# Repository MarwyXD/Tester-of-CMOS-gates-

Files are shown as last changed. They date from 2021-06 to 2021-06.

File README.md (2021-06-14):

# Tester-of-CMOS-gates-
# This is the tester of CMOS gates, they’re used a lot in electronics so i said to myself that i could create one, the reason i’m giving it online is that you all can later create code for your own CMOS gates, couse i only created program for six gates (7432, 7408, 4001, 7400, 7420, 7404/7414), i will later work on some more codes for this tester too, but for now i’ll keep it up to you, if you will create code for some more gates.

# As i mentioned in the discription of the eagle files, you should only use the .sch file, the board isn’t finished, it is due to i selected to only route the bottom layer (i dont have any PCBs with two layers), but you can create gerber files and send it for example to JLC PCB, they will do it very precisly (probably).

# The tester_CMOS_hradel.ino file is my original code for the tester. 

# Thank you.

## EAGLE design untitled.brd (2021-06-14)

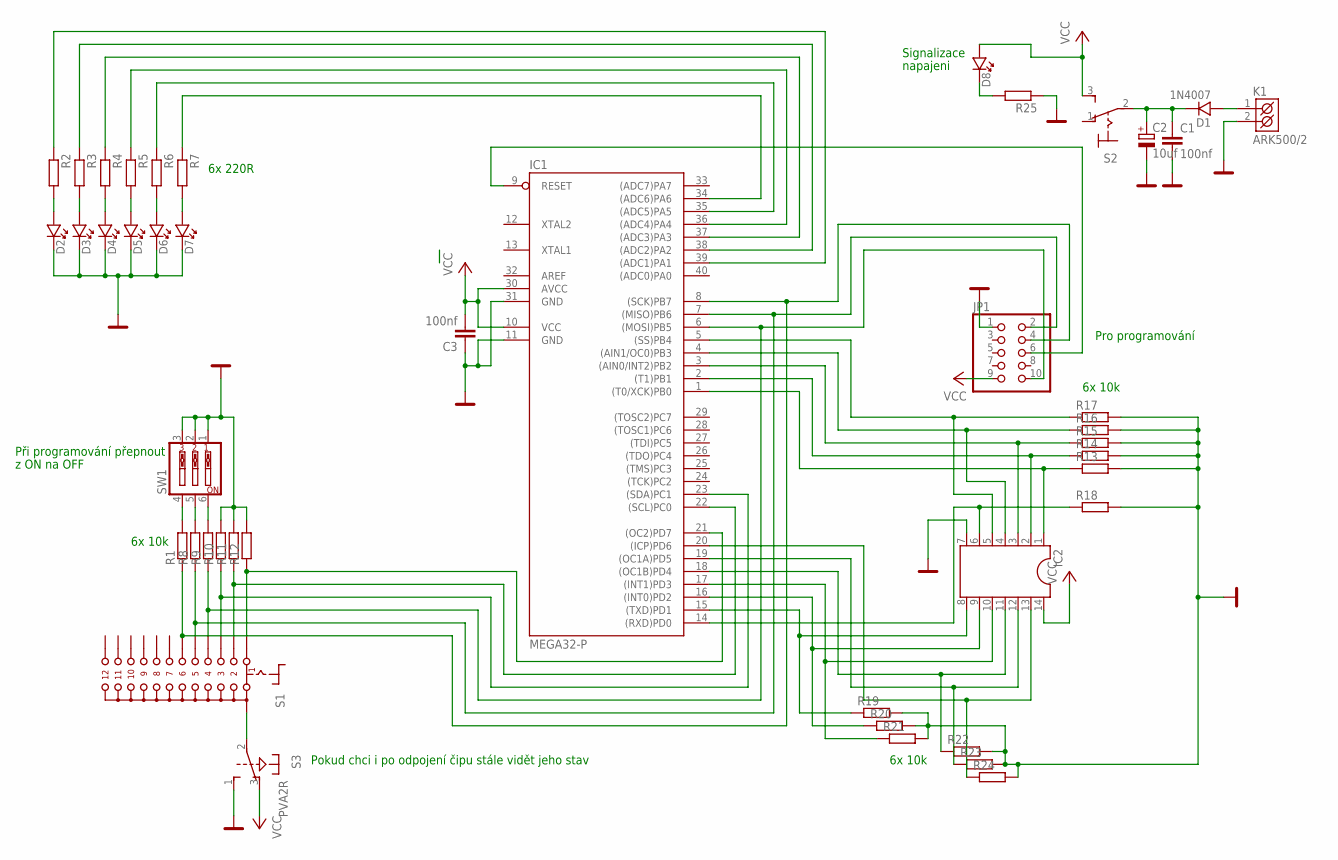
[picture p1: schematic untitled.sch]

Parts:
C1, C3: 100nf; C050-025X075
C2: 10uf; E5-8,5
D1: 1N4007; DO41
D2, D3, D4, D5, D6, D7, D8: LED_5
IC1: MEGA32-P; DIL40
IC2: DIL14
JP1: PINHD-2X5; 2X05
K1: ARK500/2
R1, R2, R3, R4, R5, R6, R7, R8, R9, R10, R11, R12, R13, R14, R15, R16, R17, R18, R19, R20, R21, R22, R23, R24, R25: R-EU_0207/10; 0207/10
S1: CK101X12
S2: 320-916
S3: PVA2R
SW1: SW_DIP-3; EDG-03

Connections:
GND: C1.2, C2.-, C3.1, D2.K, D3.K, D4.K, D5.K, D6.K, D7.K, IC1.11 (GND), IC1.31 (GND), IC2.7, JP1.1, K1.2 (K2), R10.2, R11.2, R12.2, R13.2, R14.2, R15.2, R16.2, R17.2, R18.2, R19.2, R20.2, R21.2, R22.2, R23.2, R24.2, R25.1, S3.1 (S), SW1.1, SW1.2, SW1.3
unnamed: R1.2, SW1.4
unnamed: D2.A, R2.2
unnamed: D3.A, R3.2
unnamed: D4.A, R4.2
unnamed: S1.A, S3.2
unnamed: IC1.1 ((T0/XCK)PB0), IC2.1, R13.1
unnamed: IC1.8 ((SCK)PB7), JP1.4, R1.1, S1.6
unnamed: IC1.9 (RESET), JP1.6
unnamed: D5.A, R5.2
unnamed: R8.2, SW1.5
unnamed: R9.2, SW1.6
unnamed: D6.A, R6.2
unnamed: D7.A, R7.2
unnamed: IC1.39 ((ADC1)PA1), R2.1
unnamed: IC1.38 ((ADC2)PA2), R3.1
unnamed: IC1.37 ((ADC3)PA3), R4.1
unnamed: IC1.36 ((ADC4)PA4), R5.1
unnamed: IC1.35 ((ADC5)PA5), R6.1
unnamed: IC1.34 ((ADC6)PA6), R7.1
unnamed: IC1.2 ((T1)PB1), IC2.2, R14.1
unnamed: IC1.7 ((MISO)PB6), JP1.2, R8.1, S1.5
unnamed: IC1.6 ((MOSI)PB5), JP1.10, R9.1, S1.4
unnamed: IC1.23 ((SDA)PC1), R10.1, S1.3
unnamed: IC1.22 ((SCL)PC0), R11.1, S1.2
unnamed: IC1.21 ((OC2)PD7), R12.1, S1.1
unnamed: IC1.3 ((AIN0/INT2)PB2), IC2.3, R15.1
unnamed: IC1.4 ((AIN1/OC0)PB3), IC2.4, R16.1
unnamed: IC1.5 ((SS)PB4), IC2.5, R17.1
unnamed: IC1.14 ((RXD)PD0), IC2.6, R18.1
unnamed: C1.1, C2.+, D1.K, S2.2
unnamed: D1.A, K1.1 (K1)
unnamed: IC1.15 ((TXD)PD1), IC2.8, R19.1
unnamed: IC1.16 ((INT0)PD2), IC2.9, R20.1
unnamed: IC1.17 ((INT1)PD3), IC2.10, R21.1
unnamed: IC1.18 ((OC1B)PD4), IC2.11, R22.1
unnamed: IC1.19 ((OC1A)PD5), IC2.12, R23.1
unnamed: IC1.20 ((ICP)PD6), IC2.13, R24.1
unnamed: D8.K, R25.2
VCC: C3.2, D8.A, IC1.10 (VCC), IC1.30 (AVCC), IC2.14, JP1.9, S2.3 (S), S3.3 (O)

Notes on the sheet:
6x 10k
6x 220R
Při programování přepnout
z ON na OFF
Pokud chci i po odpojení čipu stále vidět jeho stav
Signalizace
napajeni
Pro programování

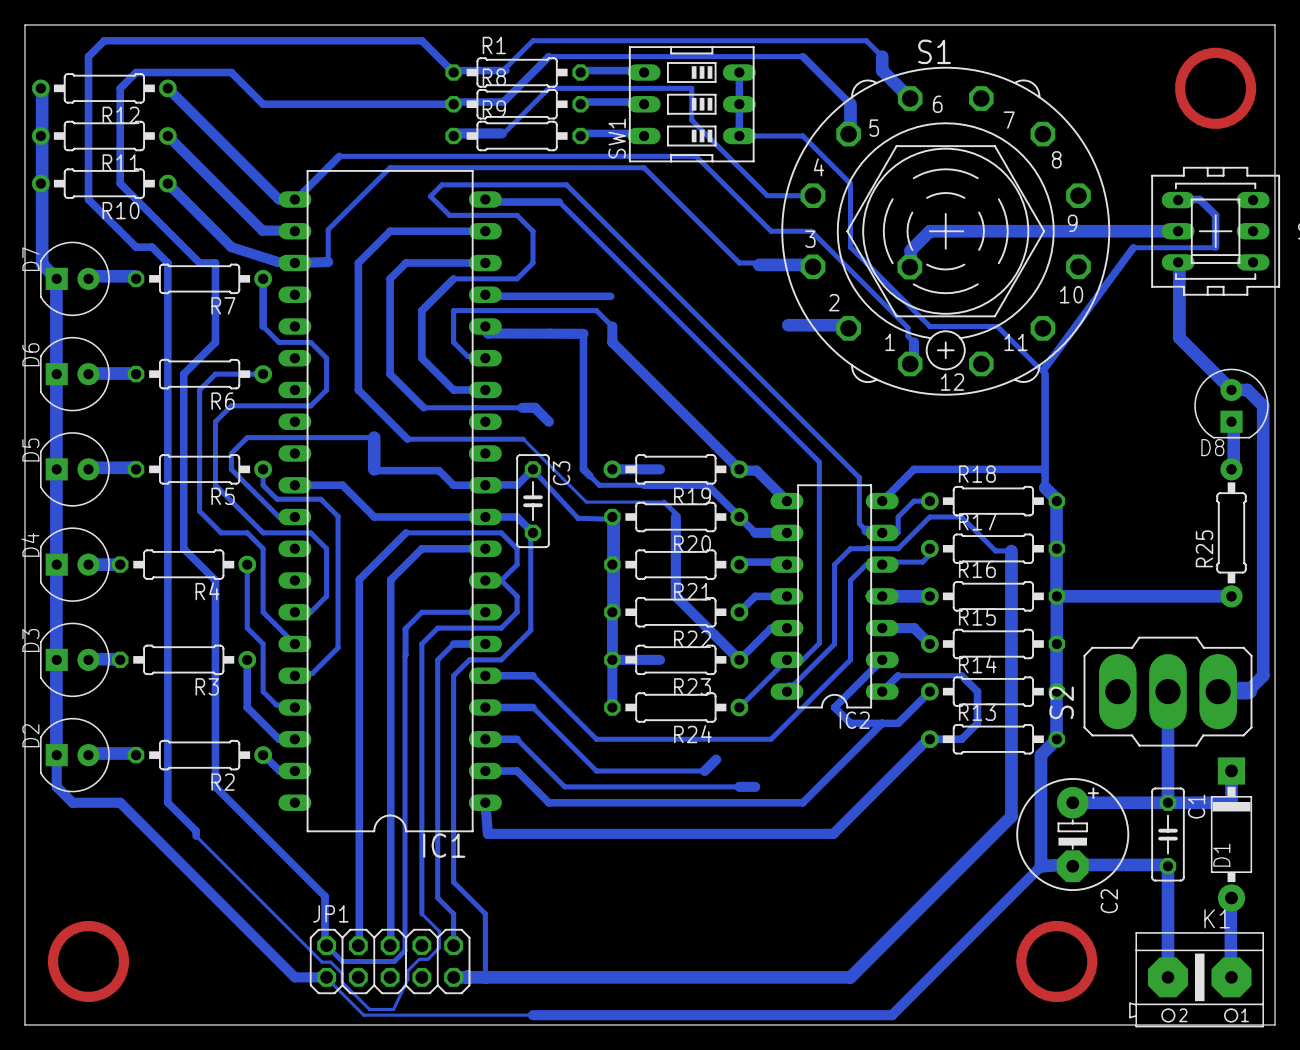
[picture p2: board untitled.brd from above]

Board: 2 copper layers, 100.0 x 80.0 mm, 44 parts (0 on the bottom side), 40 nets.

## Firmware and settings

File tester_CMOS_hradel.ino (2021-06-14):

//piny a proměnné pro čtení vstupů
int tlacitko_1 = 15;
int tlacitko_2 = 16;
int tlacitko_3 = 17;
int tlacitko_4 = 5;
int tlacitko_5 = 6;
int tlacitko_6 = 7;

//piny pro signalizaci 
int prvni_hradlo = 30;
int druhy_hradlo = 29;
int treti_hradlo = 28;
int ctvrty_hradlo = 27;
int paty_hradlo = 26;
int sesty_hradlo = 25;

//piny pro testování
int test_1 = 0;
int test_2 = 1;
int test_3 = 2;
int test_4 = 3;
int test_5 = 4;
int test_6 = 8;
int test_7 = 9;
int test_8 = 10;
int test_9 = 11;
int test_10 = 12;
int test_11= 13;
int test_12 = 14;


void setup() {
  // put your setup code here, to run once:

//tlacitko
pinMode(tlacitko_1, INPUT);
pinMode(tlacitko_2, INPUT);
pinMode(tlacitko_3, INPUT);
pinMode(tlacitko_4, INPUT);
pinMode(tlacitko_5, INPUT);
pinMode(tlacitko_6, INPUT);

//zobrazovani stavů
pinMode(prvni_hradlo, OUTPUT);
pinMode(druhy_hradlo, OUTPUT);
pinMode(treti_hradlo, OUTPUT);
pinMode(ctvrty_hradlo, OUTPUT);
pinMode(paty_hradlo, OUTPUT);
pinMode(sesty_hradlo, OUTPUT);

}

void loop() {
  // put your main code here, to run repeatedly:

int tlacitko_1_state = digitalRead(tlacitko_1);
int tlacitko_2_state = digitalRead(tlacitko_2);
int tlacitko_3_state = digitalRead(tlacitko_3);
int tlacitko_4_state = digitalRead(tlacitko_4);
int tlacitko_5_state = digitalRead(tlacitko_5);
int tlacitko_6_state = digitalRead(tlacitko_6);

//OR (7432)
if(tlacitko_1_state == HIGH && tlacitko_2_state == LOW && tlacitko_3_state == LOW && tlacitko_4_state == LOW && tlacitko_5_state == LOW && tlacitko_6_state == LOW){
  OR();
}
//AND (----)
else if(tlacitko_1_state == LOW && tlacitko_2_state == HIGH && tlacitko_3_state == LOW && tlacitko_4_state == LOW && tlacitko_5_state == LOW && tlacitko_6_state == LOW){
  AND(); 
}
//NOR (4001)
else if(tlacitko_1_state == LOW && tlacitko_2_state == LOW && tlacitko_3_state == HIGH && tlacitko_4_state == LOW && tlacitko_5_state == LOW && tlacitko_6_state == LOW){
  NOR(); 
}
//NAND (7400)
else if(tlacitko_1_state == LOW && tlacitko_2_state == LOW && tlacitko_3_state == LOW && tlacitko_4_state == HIGH && tlacitko_5_state == LOW && tlacitko_6_state == LOW){
  NAND();
}
//4NAND (7420)
else if(tlacitko_1_state == LOW && tlacitko_2_state == LOW && tlacitko_3_state == LOW && tlacitko_4_state == LOW && tlacitko_5_state == HIGH && tlacitko_6_state == LOW){
  NAND4();
}
//INV (7404/7414)
else if(tlacitko_1_state == LOW && tlacitko_2_state == LOW && tlacitko_3_state == LOW && tlacitko_4_state == LOW && tlacitko_5_state == LOW && tlacitko_6_state == HIGH){
  INV();
}

}

void OR(){                                            //Inputy jsou Dig. piny 2, 8, 9, 12

  digitalWrite(paty_hradlo, LOW);
  digitalWrite(sesty_hradlo, LOW);
  
  //definice pinů pro testy
  pinMode(test_1, OUTPUT);
  pinMode(test_2, OUTPUT);
  pinMode(test_3, INPUT);
  int test_3_state = digitalRead(test_3);

  pinMode(test_4, OUTPUT);
  pinMode(test_5, OUTPUT);
  pinMode(test_6, INPUT);
  int test_6_state = digitalRead(test_6);
  
  pinMode(test_9, OUTPUT);
  pinMode(test_8, OUTPUT);
  pinMode(test_7, INPUT);
  int test_7_state = digitalRead(test_7);

  pinMode(test_12, OUTPUT);
  pinMode(test_11, OUTPUT);
  pinMode(test_10, INPUT);
  int test_10_state = digitalRead(test_10);

  digitalWrite(test_1, HIGH);
  digitalWrite(test_2, HIGH);
  digitalWrite(test_4, HIGH);
  digitalWrite(test_5, HIGH);
  digitalWrite(test_9, HIGH);
  digitalWrite(test_8, HIGH);
  digitalWrite(test_12, HIGH);
  digitalWrite(test_11, HIGH);

  if(test_3_state == HIGH){
    digitalWrite(prvni_hradlo, HIGH);
  }
  else{
    digitalWrite(prvni_hradlo, LOW);
  }

  if(test_6_state == HIGH){
    digitalWrite(druhy_hradlo, HIGH);
  }
  else{
    digitalWrite(druhy_hradlo, LOW);
  }

  if(test_7_state == HIGH){
    digitalWrite(treti_hradlo, HIGH);
  }
  else{
    digitalWrite(treti_hradlo, LOW);
  }

  if(test_10_state == HIGH){
    digitalWrite(ctvrty_hradlo, HIGH);
  }
  else{
    digitalWrite(ctvrty_hradlo, LOW);
  }
 
}

void AND(){                                                //Inputy jsou Dig. piny 2, 8, 9, 12

  digitalWrite(paty_hradlo, LOW);
  digitalWrite(sesty_hradlo, LOW);
  
  //definice pinů pro testy
  pinMode(test_1, OUTPUT);
  pinMode(test_2, OUTPUT);
  pinMode(test_3, INPUT);
  int test_3_state = digitalRead(test_3);

  pinMode(test_4, OUTPUT);
  pinMode(test_5, OUTPUT);
  pinMode(test_6, INPUT);
  int test_6_state = digitalRead(test_6);
  
  pinMode(test_9, OUTPUT);
  pinMode(test_8, OUTPUT);
  pinMode(test_7, INPUT);
  int test_7_state = digitalRead(test_7);

  pinMode(test_12, OUTPUT);
  pinMode(test_11, OUTPUT);
  pinMode(test_10, INPUT);
  int test_10_state = digitalRead(test_10);

  digitalWrite(test_1, HIGH);
  digitalWrite(test_2, HIGH);
  digitalWrite(test_4, HIGH);
  digitalWrite(test_5, HIGH);
  digitalWrite(test_9, HIGH);
  digitalWrite(test_8, HIGH);
  digitalWrite(test_12, HIGH);
  digitalWrite(test_11, HIGH);

  if(test_3_state == HIGH){
    digitalWrite(prvni_hradlo, HIGH);
  }
  else{
    digitalWrite(prvni_hradlo, LOW);
  }

  if(test_6_state == HIGH){
    digitalWrite(druhy_hradlo, HIGH);
  }
  else{
    digitalWrite(druhy_hradlo, LOW);
  }

  if(test_7_state == HIGH){
    digitalWrite(treti_hradlo, HIGH);
  }
  else{
    digitalWrite(treti_hradlo, LOW);
  }

  if(test_10_state == HIGH){
    digitalWrite(ctvrty_hradlo, HIGH);
  }
  else{
    digitalWrite(ctvrty_hradlo, LOW);
  }
}

void NOR(){

  digitalWrite(paty_hradlo, LOW);
  digitalWrite(sesty_hradlo, LOW);
  
  //definice pinů pro testy
  pinMode(test_1, OUTPUT);
  pinMode(test_2, OUTPUT);
  pinMode(test_3, INPUT);
  int test_3_state = digitalRead(test_3);

  pinMode(test_6, OUTPUT);
  pinMode(test_5, OUTPUT);
  pinMode(test_4, INPUT);
  int test_4_state = digitalRead(test_4);
  
  pinMode(test_7, OUTPUT);
  pinMode(test_8, OUTPUT);
  pinMode(test_9, INPUT);
  int test_9_state = digitalRead(test_9);

  pinMode(test_12, OUTPUT);
  pinMode(test_11, OUTPUT);
  pinMode(test_10, INPUT);
  int test_10_state = digitalRead(test_10);

  digitalWrite(test_1, LOW);
  digitalWrite(test_2, LOW);
  digitalWrite(test_6, LOW);
  digitalWrite(test_5, LOW);
  digitalWrite(test_7, LOW);
  digitalWrite(test_8, LOW);
  digitalWrite(test_12, LOW);
  digitalWrite(test_11, LOW);

  if(test_3_state == HIGH){
    digitalWrite(prvni_hradlo, HIGH);
  }
  else{
    digitalWrite(prvni_hradlo, LOW);
  }

  if(test_4_state == HIGH){
    digitalWrite(druhy_hradlo, HIGH);
  }
  else{
    digitalWrite(druhy_hradlo, LOW);
  }

  if(test_9_state == HIGH){
    digitalWrite(treti_hradlo, HIGH);
  }
  else{
    digitalWrite(treti_hradlo, LOW);
  }

  if(test_10_state == HIGH){
    digitalWrite(ctvrty_hradlo, HIGH);
  }
  else{
    digitalWrite(ctvrty_hradlo, LOW);
  }
}
  
void NAND(){

  digitalWrite(paty_hradlo, LOW);
  digitalWrite(sesty_hradlo, LOW);
  
  //definice pinů pro testy
  pinMode(test_1, OUTPUT);
  pinMode(test_2, OUTPUT);
  pinMode(test_3, INPUT);
  int test_3_state = digitalRead(test_3);

  pinMode(test_4, OUTPUT);
  pinMode(test_5, OUTPUT);
  pinMode(test_6, INPUT);
  int test_6_state = digitalRead(test_6);
  
  pinMode(test_9, OUTPUT);
  pinMode(test_8, OUTPUT);
  pinMode(test_7, INPUT);
  int test_7_state = digitalRead(test_7);

  pinMode(test_12, OUTPUT);
  pinMode(test_11, OUTPUT);
  pinMode(test_10, INPUT);
  int test_10_state = digitalRead(test_10);

  digitalWrite(test_1, LOW);
  digitalWrite(test_2, LOW);
  digitalWrite(test_4, LOW);
  digitalWrite(test_5, LOW);
  digitalWrite(test_9, LOW);
  digitalWrite(test_8, LOW);
  digitalWrite(test_12, LOW);
  digitalWrite(test_11, HIGH);

  if(test_3_state == HIGH){
    digitalWrite(prvni_hradlo, HIGH);
  }
  else{
    digitalWrite(prvni_hradlo, LOW);
  }

  if(test_6_state == HIGH){
    digitalWrite(druhy_hradlo, HIGH);
  }
  else{
    digitalWrite(druhy_hradlo, LOW);
  }

  if(test_7_state == HIGH){
    digitalWrite(treti_hradlo, HIGH);
  }
  else{
    digitalWrite(treti_hradlo, LOW);
  }

  if(test_10_state == HIGH){
    digitalWrite(ctvrty_hradlo, HIGH);
  }
  else{
    digitalWrite(ctvrty_hradlo, LOW);
  }
}

void NAND4(){

  digitalWrite(treti_hradlo, LOW);
  digitalWrite(ctvrty_hradlo, LOW);
  digitalWrite(paty_hradlo, LOW);
  digitalWrite(sesty_hradlo, LOW);
  
  pinMode(test_1, OUTPUT);
  pinMode(test_2, OUTPUT);
  pinMode(test_4, OUTPUT);
  pinMode(test_5, OUTPUT);
  pinMode(test_6, INPUT);
  int test_6_state = digitalRead(test_6);

  pinMode(test_7, INPUT);
  pinMode(test_8, OUTPUT);
  pinMode(test_9, OUTPUT);
  pinMode(test_11, OUTPUT);
  pinMode(test_12, OUTPUT);
  int test_7_state = digitalRead(test_7);

  digitalWrite(test_1, LOW);
  digitalWrite(test_2, LOW);
  digitalWrite(test_4, LOW);
  digitalWrite(test_5, LOW);
  digitalWrite(test_9, LOW);
  digitalWrite(test_8, LOW);
  digitalWrite(test_12, LOW);
  digitalWrite(test_11, LOW);

  if(test_6_state == HIGH){
    digitalWrite(prvni_hradlo, HIGH);
  }
  else{
    digitalWrite(prvni_hradlo, LOW);
  }

  if(test_7_state == HIGH){
    digitalWrite(druhy_hradlo, HIGH);
  }
  else{
    digitalWrite(druhy_hradlo, LOW);
  }
  
}

void INV(){
  pinMode(test_1, OUTPUT);
  pinMode(test_2, INPUT);
  int test_2_state = digitalRead(test_2);

  pinMode(test_3, OUTPUT);
  pinMode(test_4, INPUT);
  int test_4_state = digitalRead(test_4);

  pinMode(test_5, OUTPUT);
  pinMode(test_6, INPUT);
  int test_6_state = digitalRead(test_6);

  pinMode(test_7, INPUT);
  pinMode(test_8, OUTPUT);
  int test_7_state = digitalRead(test_7);

  pinMode(test_9, INPUT);
  pinMode(test_10, OUTPUT);
  int test_9_state = digitalRead(test_9);

  pinMode(test_11, INPUT);
  pinMode(test_12, OUTPUT);
  int test_11_state = digitalRead(test_11);

  digitalWrite(test_1, LOW);
  digitalWrite(test_3, LOW);
  digitalWrite(test_5, LOW);
  digitalWrite(test_7, LOW);
  digitalWrite(test_9, LOW);
  digitalWrite(test_11, LOW);

  if(test_2_state == HIGH){
    digitalWrite(prvni_hradlo, HIGH);
  }
  else{
    digitalWrite(prvni_hradlo, LOW);
  }

  if(test_4_state == HIGH){
    digitalWrite(druhy_hradlo, HIGH);
  }
  else{
    digitalWrite(druhy_hradlo, LOW);
  }

  if(test_6_state == HIGH){
    digitalWrite(treti_hradlo, HIGH);
  }
  else{
    digitalWrite(treti_hradlo, LOW);
  }

  if(test_7_state == HIGH){
    digitalWrite(ctvrty_hradlo, HIGH);
  }
  else{
    digitalWrite(ctvrty_hradlo, LOW);
  }

  if(test_9_state == HIGH){
    digitalWrite(paty_hradlo, HIGH);
  }
  else{
    digitalWrite(paty_hradlo, LOW);
  }

  if(test_11_state == HIGH){
    digitalWrite(sesty_hradlo, HIGH);
  }
  else{
    digitalWrite(sesty_hradlo, LOW);
  }
  
}

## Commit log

2021-06-14 The documentation for the IO’s
2021-06-14 Schematics and board layout in eagle
    This is what i create for it, firstly i want to recomend to you to only use the .sch file, you can create your own PCB, there are some traces that even the autorouter wasn’t able to do (unrouted), so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
    [untitled.brd, untitled.sch]

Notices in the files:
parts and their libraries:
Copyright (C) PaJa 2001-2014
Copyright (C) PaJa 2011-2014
